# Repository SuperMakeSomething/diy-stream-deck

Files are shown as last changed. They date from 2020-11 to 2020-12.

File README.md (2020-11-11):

# DIY Stream Deck
by: Alex - Super Make Something

date: November 9, 2020

license: Creative Commons - Attribution - Non-Commercial.  More information available at: http://creativecommons.org/licenses/by-nc/3.0/

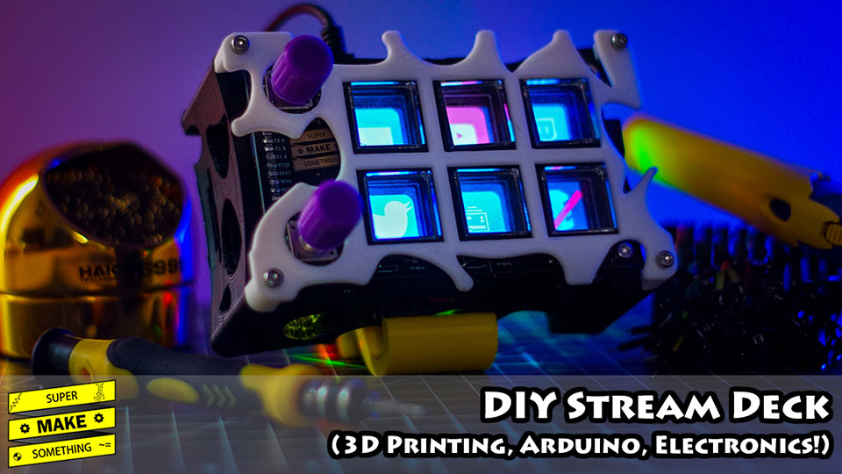
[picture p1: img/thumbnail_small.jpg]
Banner


Arduino code, icon templates, and programming instructions for the DIY Stream Deck featured in Super Make Something Episode 22!

The project video can be found [here](https://youtu.be/_NqYtvLnY5k)!

If you like projects like these, consider subscribing to the Super Make Something YouTube page [here](https://www.youtube.com/supermakesomething?sub_confirmation=1) for more cool builds!  To support more projects like this please consider becoming a [Patron](https://www.patreon.com/SuperMakeSomething).

## Introduction
Arguably one of the best streaming tools besides a camera, microphone, and lights is a Stream Deck, a macro keyboard with an LCD screen behind the buttons, which allows users to program custom shortcuts to control their streaming software and various other applications.  Unfortunately this surge in interest has made these devices either difficult to find or very expensive.  Because of this, I decided to create an open source version, which will hopefully make it easier for those interesting in streaming to go live online, and to make it possible for individuals to create the custom Stream Deck that best suits their streaming needs.

This repository contains code and icon templates required to build your own DIY Stream Deck.  Information found in this repository accompanies the "DIY Stream Deck" build video on the Super Make Something YouTube page, which can be found here.

## Installation instructions and required libraries
Write-up coming soon!  In the meantime, please check out the project video [here](https://youtu.be/_NqYtvLnY5k) for step-by-step instructions about how to build this project.

## Bill of materials
- PCBs: https://bit.ly/2JKsyOw
- 3D Printed Files: https://www.thingiverse.com/thing:4650060
- 3.5in TFT LCD Screen: https://amzn.to/3ke75tS
- Arduino Pro Micro: https://amzn.to/35e6Vys
- Arduino Nano: https://amzn.to/3eHZF0K
- SD Card Breakout Board: https://amzn.to/3kb2Orj
- 6mm Push-Buttons: https://amzn.to/2Ilm4VO
- Rotary Encoder with Push-Button: https://amzn.to/35j7Xtf
- Male/Female Header Kit: https://amzn.to/35ezw6T
- Ribbon Cable: https://amzn.to/2GPOrLq
- 4GB Micro SD Card: https://amzn.to/35eC2tS
- M2 Screw Kit: https://amzn.to/2GKlz77
- M3 Screw Kit: https://amzn.to/2GNitiQ
- Hatchbox Black PLA: https://amzn.to/35fGM2h
- Hatchbox White PLA: https://amzn.to/2InWG1n
- Color Changing PLA: https://amzn.to/35fNuoM
- Resistor Kit (Optional): https://amzn.to/2UcVQY2
- Slow Flash RGB LEDs (Optional): https://amzn.to/2Uep7l2
- 20x20mm Acrylic Squares: https://litko.net/

(All Amazon links are affiliate links.)

## Conclusion
Hopefully you found this project useful!  If you enjoyed this tutorial, consider subscribing to Super Make Something on YouTube [here](https://www.youtube.com/supermakesomething?sub_confirmation=1) for more cool builds!  If you _really_ liked this tutorial and want to support future projects, you can become a [patron on Patreon](https://www.patreon.com/SuperMakeSomething).

If you have any questions or comments, I can most easily be reached on [Twitter](https://twitter.com/supermakesmthng) or [Instagram](https://www.instagram.com/supermakesomething/).  For items or issues specifically related to this project, please leaving your questions in the comments of the accompanying YouTube video so that they can be referenced by others during their own builds.

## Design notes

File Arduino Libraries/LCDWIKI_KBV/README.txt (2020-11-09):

This is a library for the lcd display.
This library support these lcd controller:
ILI9325 
ILI9328 
ILI9341 
HX8357D 
HX8347G 
HX8347I 
ILI9486 
ST7735S 
 
Check out the file of LCDWIKI KBV lib Requirements for our tutorials and wiring diagrams.

These displays use 8-bit and 16-bit parallel to communicate, 12 or 13 pins are required to interface (RST is optional).
check out the file of lcd_mode.h for switching between 8bit mode and 16 bit mode.
Basic functionally of this library was origianlly based on the demo-code of Adafruit GFX lib and Adafruit TFTLCD lib.  

MIT license, all text above must be included in any redistribution

To download. click the DOWNLOADS button in the top right corner, rename the uncompressed folder LCDWIKI_KBV. Check that the LCDWIKI_KBV folder contains LCDWIKI_KBV.cpp and LCDWIKI_KBV.h

Place the LCDWIKI_KBV library folder your <arduinosketchfolder>/libraries/ folder. You may need to create the libraries subfolder if its your first library. Restart the IDE

Also requires the LCDWIKI_GUI library for Arduino. 
https://github.com/lcdwiki/LCDWIKI_gui

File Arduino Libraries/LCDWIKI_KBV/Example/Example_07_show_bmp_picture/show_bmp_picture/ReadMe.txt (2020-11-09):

ReadMe:
"ShowBMP"example need to read BMP files from SDcard.
so, firstly,you should format your SD-card into fat16 or fat32.
then copy the flower.bmp,RedRose.bmp,tiger.bmp,tree.bmp into your SD-card.

Attention:
This Example only support the Arduino UNO board,not support the Mega2560,Because they use different SPI bus.

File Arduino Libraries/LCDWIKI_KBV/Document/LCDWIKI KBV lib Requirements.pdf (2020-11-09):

# LCDWIKI KBV lib Requirements

the 8bit mode connections for shield

Lcd modules pin | Arduino
UNO | MEGA
LCD_D0 | D8 | D8
LCD_D1 | D9 | D9
LCD_D2 | D10 | D10
LCD_D3 | D11 | D11
LCD_D4 | D4 | D4
LCD_D5 | D13 | D13
LCD_D6 | D6 | D6
LCD_D7 | D7 | D7
LCD_RST | D5 | D5
LCD_CS | A3 | A3
LCD_RS | A2 | A2
LCD_WR | A1 | A1
LCD_RD | A0 | A0

the 8bit mode connections for breakout board

Lcd modules pin | Arduino
UNO | MEGA
LCD_D0 | D8 | D8
LCD_D1 | D9 | D9
LCD_D2 | D2 | D2
LCD_D3 | D3 | D3
LCD_D4 | D4 | D4
LCD_D5 | D5 | D5
LCD_D6 | D6 | D6
LCD_D7 | D7 | D7
LCD_RST | Any free pin
LCD_CS | Any free pin
LCD_RS | Any free pin
LCD_WR | Any free pin
LCD_RD | Any free pin

In this library,the 16bit mode only can use in Arduino Mega board.

the 16bit mode connections for shield and breakout board

Lcd modules pin | Arduino MEGA
shield | breakout board
DB0 | D37 | D37
DB1 | D36 | D36
DB2 | D35 | D35
DB3 | D34 | D34
DB4 | D33 | D33
DB5 | D32 | D32
DB6 | D31 | D31
DB7 | D30 | D30
DB8 | D22 | D22
DB9 | D23 | D23
DB10 | D24 | D24
DB11 | D25 | D25
DB12 | D26 | D26
DB13 | D27 | D27
DB14 | D28 | D28
DB15 | D29 | D29
RST | D5 | Any free pin
CS | D41 | Any free pin
RS | D38 | Any free pin
WR | D40 | Any free pin
RD | D43 | Any free pin

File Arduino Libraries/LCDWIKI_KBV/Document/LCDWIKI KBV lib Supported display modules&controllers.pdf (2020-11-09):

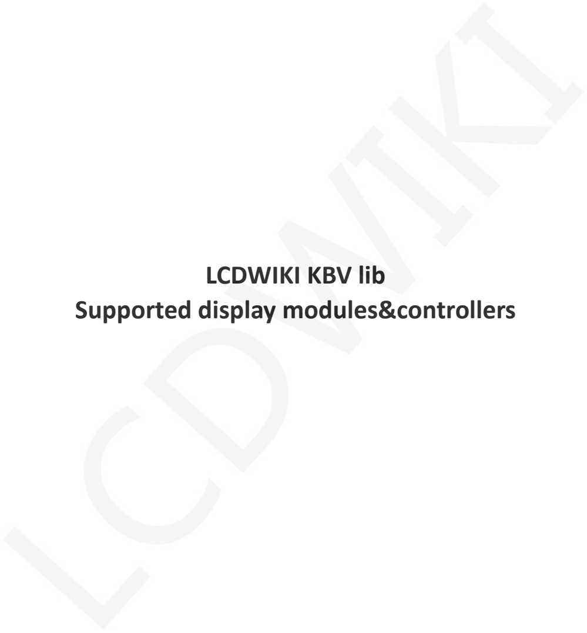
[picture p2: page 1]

# LCDWIKI KBV lib Supported display modules&controllers

### 1. IMPORTANT

### 2. Supported display modules&controllers

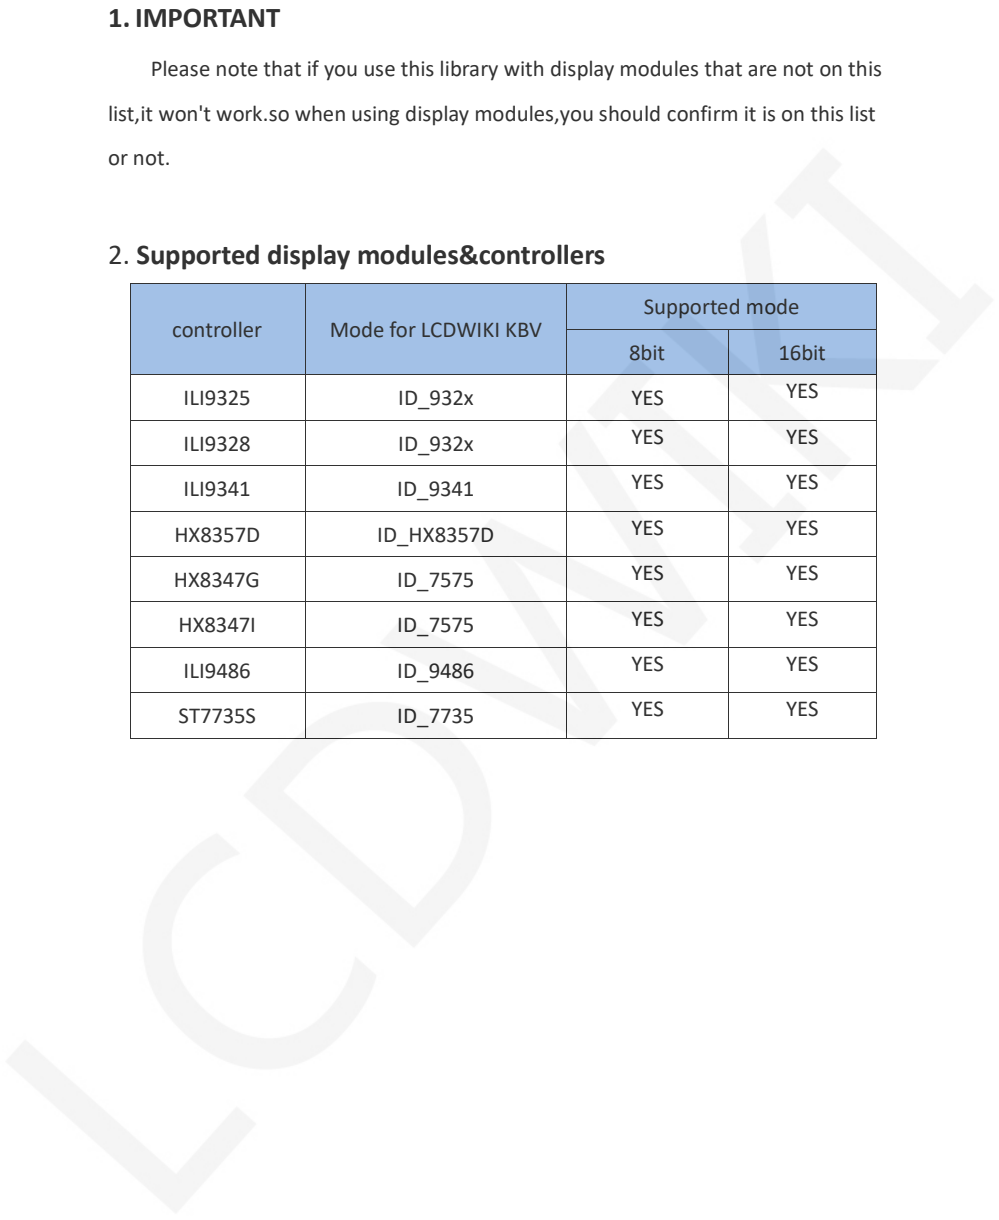
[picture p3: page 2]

Please note that if you use this library with display modules that are not on this

list,it won't work.so when using display modules,you should confirm it is on this list

or not.

controller | Mode for LCDWIKI KBV | Supported mode
8bit | 16bit
ILI9325 | ID_932x | YES | YES
ILI9328 | ID_932x | YES | YES
ILI9341 | ID_9341 | YES | YES
HX8357D | ID_HX8357D | YES | YES
HX8347G | ID_7575 | YES | YES
HX8347I | ID_7575 | YES | YES
ILI9486 | ID_9486 | YES | YES
ST7735S | ID_7735 | YES | YES

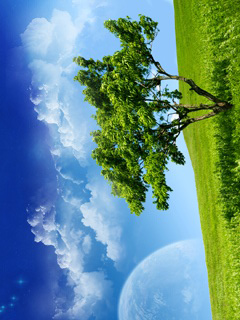
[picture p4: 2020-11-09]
Arduino Libraries/LCDWIKI_KBV/Example/Example_07_show_bmp_picture/show_bmp_picture/PIC_240x320/tree.bmp

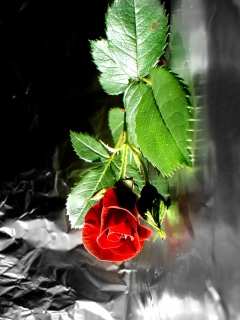
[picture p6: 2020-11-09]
Arduino Libraries/LCDWIKI_KBV/Example/Example_07_show_bmp_picture/show_bmp_picture/PIC_240x320/RedRose.bmp

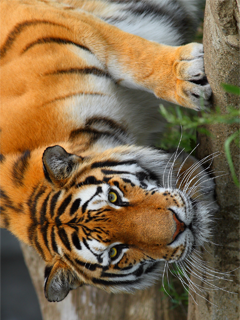
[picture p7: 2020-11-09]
Arduino Libraries/LCDWIKI_KBV/Example/Example_07_show_bmp_picture/show_bmp_picture/PIC_240x320/tiger.bmp

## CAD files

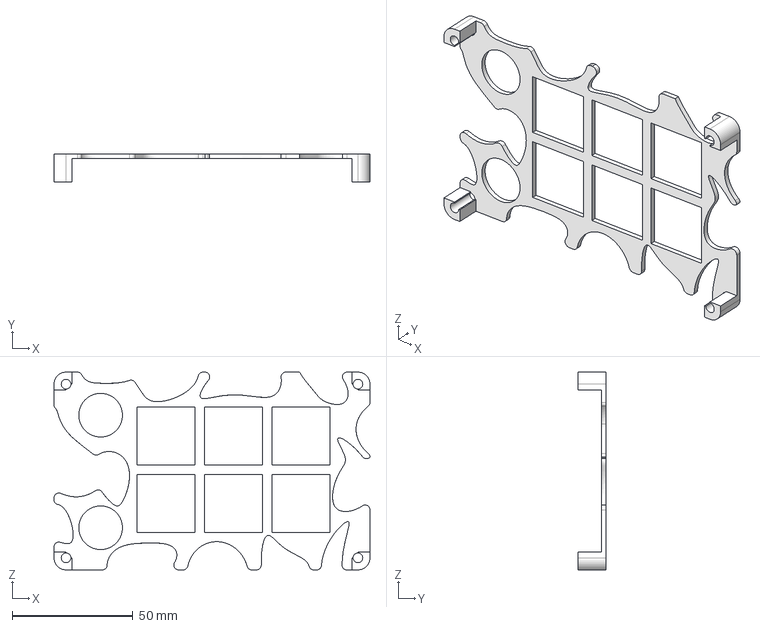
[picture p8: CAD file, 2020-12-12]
CAD/STEP Files/PM-1002 - Stream Deck Cover.step
131.0 x 11.8 x 82.0 mm

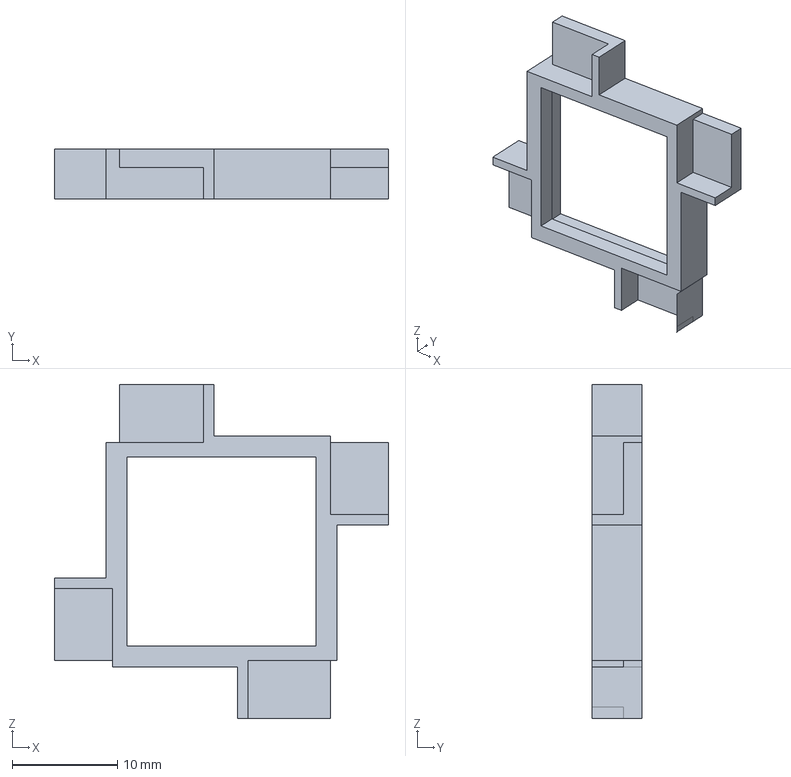
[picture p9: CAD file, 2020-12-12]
CAD/STEP Files/PM-1003 - Button Cover.step
31.8 x 4.75 x 31.8 mm

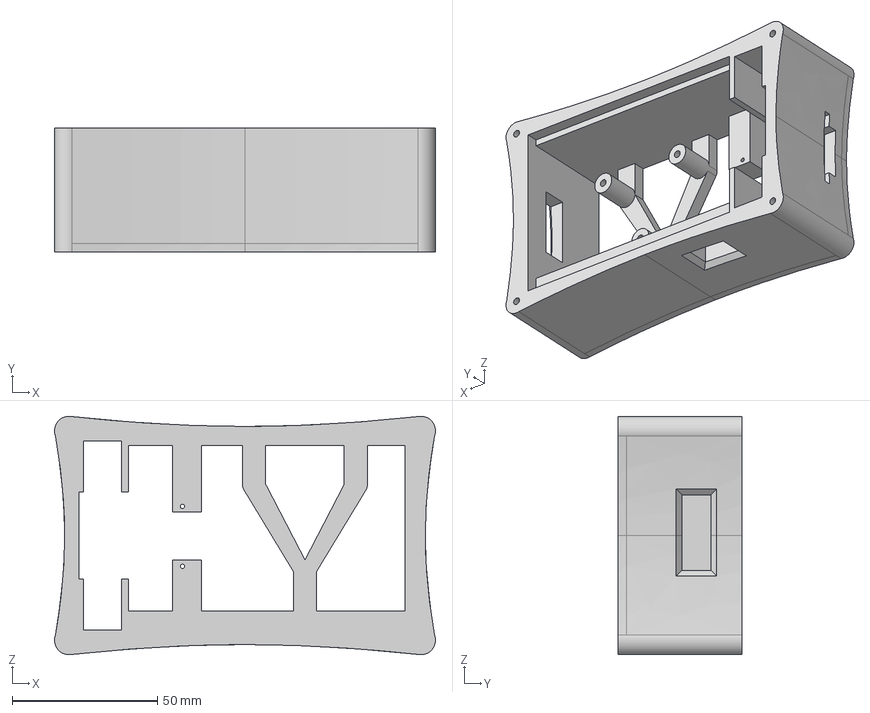
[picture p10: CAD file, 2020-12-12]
CAD/STEP Files/PM-1001a - Housing.step
131.0 x 42.8 x 82.0 mm

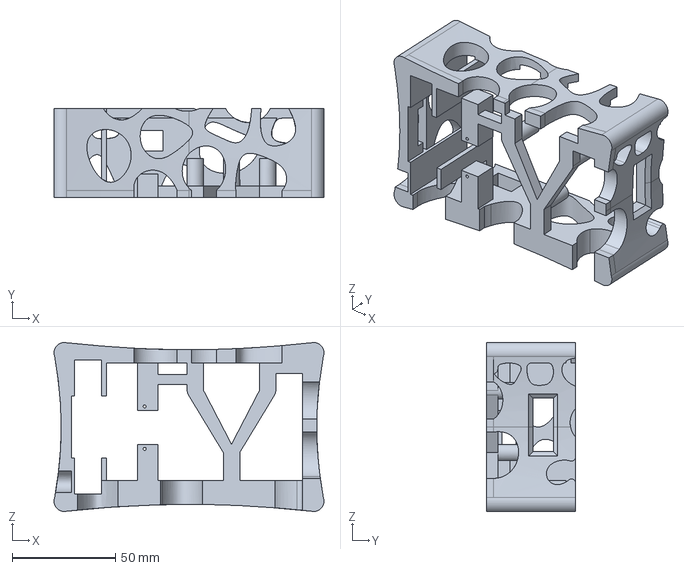
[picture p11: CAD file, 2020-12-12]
CAD/STEP Files/PM-1001b - Voronoi Housing.step
131.0 x 43.3 x 82.0 mm

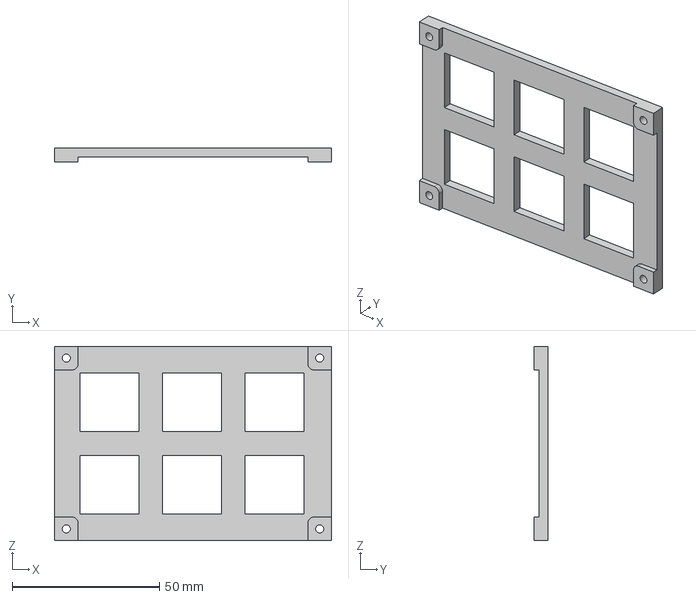
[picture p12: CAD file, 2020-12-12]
CAD/STEP Files/PM-1005 - Button PCB Spacer.step
94.0 x 4.75 x 66.0 mm

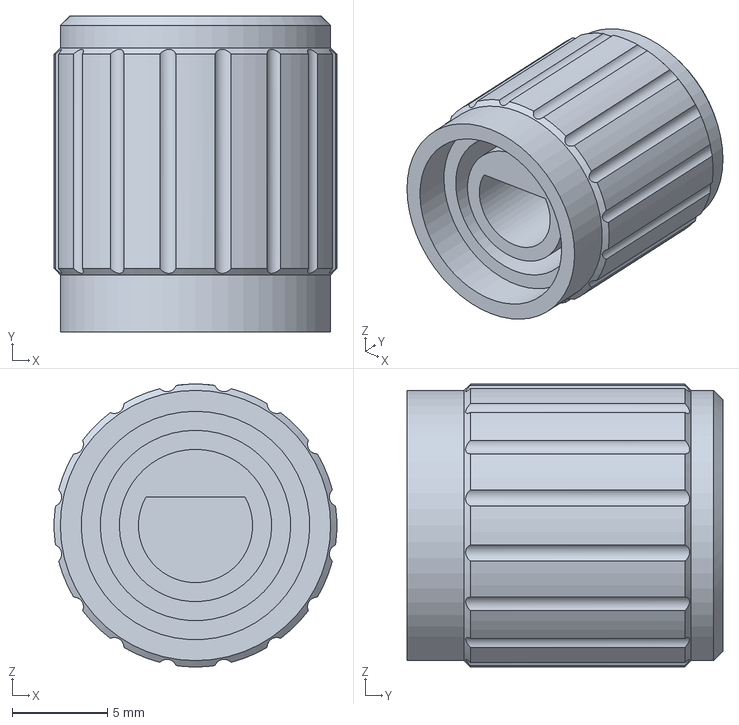
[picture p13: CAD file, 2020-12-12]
CAD/STEP Files/PM-1004 - Encoder Knob.step
14.8 x 16.6 x 14.9 mm

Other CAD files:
CAD/STL Files/PM-1001a - Housing.stl
CAD/STL Files/PM-1001b - Voronoi Housing.stl
CAD/STL Files/PM-1002 - Stream Deck Cover.stl
CAD/STL Files/PM-1003 - Button Cover.stl
CAD/STL Files/PM-1004 - Encoder Knob.stl
CAD/STL Files/PM-1005 - Button PCB Spacer.stl

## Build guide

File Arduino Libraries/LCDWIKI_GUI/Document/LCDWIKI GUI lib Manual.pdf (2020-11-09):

# LCDWIKI GUI lib Manual

### 1.Introduction

The LCDWIKI GUI lib is the core graphics library for all our displays, providing a

common set of graphics primitives (points, lines, circles, etc.). It needs to be paired

with a hardware-specific library for each display device we carry (to handle the

lower-level functions).

The LCDWIKI GUI lib have the base class.so all functions in this lib should be

called by the subclass.

### 2.FUNCTIONS DECLARATION

definiens | LCDWIKI_GUI(void)
function | The main class constructor when using 8bit or 16bit or spi display modules.
parameters | None
returned value | None
notes | None
definiens | virtual uint16_t Color_To_565(uint8_t r, uint8_t g, uint8_t b)
function | Pass three 8bits colour value and get the 16bits colour value
parameters | r : the 8bits red value g : the 8bits green value b : the 8bits blue value
returned value | The 16bits colour value(rrrrrggggggbbbbb)
notes | This is virtual function and it is defined by the subclass
definiens | virtual void Draw_Pixe(int16_t x, int16_t y, uint16_t color)
function | Using color value to draw a single point
parameters | x : the x coordinate of the piexl y : the y coordinate of the piexl color : the color value of the piexl
returned value | None
notes | This is virtual function and it is defined by the subclass

definiens | virtual void Fill_Rect(int16_t x, int16_t y, int16_t w, int16_t h, uint16_t color)
function | Using color value to draw a filled rectangle with w width and h height in x and y coordinate
parameters | x : the x coordinate of the start-corner y : the y coordinate of the start-corner w : the width of the rectangle h : the height of the rectangle color : the color value of the filled rectangle
returned value | None
notes | This is virtual function and it is defined by the subclass
definiens | virtual void Set_Addr_Window(int16_t x1, int16_t y1, int16_t x2, int16_t y2)
function | Set display area bewteen two point
parameters | x1 : the x coordinate of the start-corner y1 : the y coordinate of the start-corner x2 : the x coordinate of the end-corner y2 : the y coordinate of the end-corner
returned value | None
notes | This is virtual function and it is defined by the subclass

definiens | virtual void Push_Any_Color(uint16_t * block, int16_t n, bool first, uint8_t flags)
function | Set a large number of color values at a time
parameters | block : the array of colour values n : the number of colour values first : 1- First set the command of write color value 0-have set the command of write color value flags : 0-read color value from RAM 1-read color value from flash
returned value | None
notes | This is virtual function and it is defined by the subclass
definiens | virtual int16_t Read_GRAM(int16_t x, int16_t y, uint16_t *block, int16_t w, int16_t h)
function | Read colour value from GRAM
parameters | x : the x coordinate of the start-corner y : the y coordinate of the start-corner block : the array of saving colour value w : the width of the Read area h : the heigth of the Read area
returned value | 0-successful
notes | This is virtual function and it is defined by the subclass

definiens | virtual int16_t Get_Height(void) const
function | Get the display height
parameters | None
returned value | The diaplay height
notes | This is virtual function and it is defined by the subclass
definiens | virtual int16_t Get_Width(void) const
function | Get the display width
parameters | None
returned value | The diaplay width
notes | This is virtual function and it is defined by the subclass
definiens | void Set_Draw_color(uint16_t color)
function | Set the drawing color
parameters | color : the 16bits Drawing color value
returned value | None
notes | None
definiens | void Set_Draw_color(uint16_t color)
function | Set the drawing color
parameters | color : the 16bits Drawing color value
returned value | None

notes | None
definiens | void Set_Draw_color(uint8_t r, uint8_t g, uint8_t b)
function | Set the drawing color
parameters | r : the 8bits red value g : the 8bits green value b : the 8bits blue value
returned value | None
notes | None
definiens | uint16_t Get_Draw_color(void) const
function | get the drawing color
parameters | None
returned value | The 16bits drawing color value(rrrrrggggggbbbbb)
notes | None
definiens | void Draw_Pixel(int16_t x, int16_t y)
function | Draw a single point
parameters | x : the x coordinate of the piexl y : the y coordinate of the piexl
returned value | None
notes | None

definiens | uint16_t Read_Pixel(int16_t x, int16_t y)
function | Get the color value of a single point
parameters | x : the x coordinate of the piexl y : the y coordinate of the piexl
returned value | 16bits color value of a single point
notes | The mould must be readable,this functon can be used normally.
definiens | void Draw_Fast_VLine(int16_t x, int16_t y, int16_t h)
function | Quickly draw out a vertical line
parameters | x : the x coordinate of the start point y : the y coordinate of the start point h : the height of the line
returned value | None
notes | None
definiens | void Draw_Fast_HLine(int16_t x, int16_t y, int16_t w)
function | Quickly draw out a horizontal line
parameters | x : the x coordinate of the start point y : the y coordinate of the start point h : the width of the line
returned value | None
notes | None

definiens | void Fill_Screen(uint16_t color)
function | Fill whole screen area
parameters | color : 16bits color value
returned value | None
notes | None
definiens | void Fill_Screen(uint8_t r, uint8_t g, uint8_t b)
function | Fill whole screen area
parameters | r : the 8bits red value g : the 8bits green value b : the 8bits blue value
returned value | None
notes | The r,g,b is converted to 16bits value(rrrrrggggggbbbbb)
definiens | void Draw_Line(int16_t x1, int16_t y1, int16_t x2, int16_t y2)
function | Draw a line be
parameters | r : the 8bits red value g : the 8bits green value b : the 8bits blue value
returned value | None
notes | The r,g,b is converted to 16bits value(rrrrrggggggbbbbb)

definiens | void Draw_Rectangle(int16_t x1, int16_t y1, int16_t x2, int16_t y2)
function | Draw a rectangle between two points
parameters | x1 : the x coordinate of the start point y1 : the y coordinate of the start point x2 : the x coordinate of the end point y2 : the y coordinate of the end point
returned value | None
notes | None
definiens | void Fill_Rectangle(int16_t x1, int16_t y1, int16_t x2, int16_t y2)
function | Draw a filled rectangle between two points
parameters | x1 : the x coordinate of the start point y1 : the y coordinate of the start point x2 : the x coordinate of the end point y2 : the y coordinate of the end point
returned value | None
notes | None
definiens | void Draw_Round_Rectangle(int16_t x1, int16_t y1, int16_t x2, int16_t y2, uint8_t radius)
function | Draw a rectangle with slightly rounded corners between two points

parameters | x1 : the x coordinate of the start point y1 : the y coordinate of the start point x2 : the x coordinate of the end point y2 : the y coordinate of the end point radius : radius of the rounded corners, the minimum value is 5
returned value | None
notes | If the radius is smaller than the minimum value ,the round rectangle will not be drawn
definiens | void Fill_Round_Rectangle(int16_t x1, int16_t y1, int16_t x2,int16_t y2, int16_t radius)
function | Draw a filled rectangle with slightly rounded corners between two points
parameters | x1 : the x coordinate of the start point y1 : the y coordinate of the start point x2 : the x coordinate of the end point y2 : the y coordinate of the end point radius : radius of the rounded corners, the minimum value is 5
returned value | None
notes | If the radius is smaller than the minimum value ,the round rectangle will not be drawn
definiens | void Draw_Circle(int16_t x, int16_t y, int16_t radius)
function | Draw a circle with a specified radius
parameters | x : the x coordinate of the center of the circle y : the y coordinate of the center of the circle

| radius : radius of the circle
returned value | None
notes | None
definiens | void Draw_Circle_Helper(int16_t x0, int16_t y0, int16_t radius, uint8_t cornername)
function | Draw rounded corners with a specified radius
parameters | x0 : the x coordinate of the center of the rounded corner y0 : the y coordinate of the center of the rounded corner radius : radius of the rounded corners, the minimum value is 5 cornername : the order number of the rounded corners, 1 : top left corner 2 : top right corner 4 : lower right corner 8 : lower left quarter
returned value | None
notes | If the radius is smaller than the minimum value ,the round rectangle will not be drawn.you can draw several rounded corners at a time
definiens | void Fill_Circle(int16_t x, int16_t y, int16_t radius)
function | Draw a filled circle with a specified radius
parameters | x : the x coordinate of the center of the circle y : the y coordinate of the center of the circle radius : radius of the circle

returned value | None
notes | None
definiens | void Fill_Circle_Helper(int16_t x0, int16_t y0, int16_t r, uint8_t cornername,int16_t delta)
function | Draw filled rounded corners with a specified radius
parameters | x0 : the x coordinate of the center of the rounded corner y0 : the y coordinate of the center of the rounded corner r : radius of the rounded corner cornername : the order number of the rounded corners 1 : right rounded corner 2 : left rounded corner delta : Non - circular area height
returned value | None
notes | you can draw filled several rounded corners at a time
definiens | void Draw_Triangle(int16_t x0, int16_t y0, int16_t x1, int16_t y1,int16_t x2, int16_t y2)
function | Draw a triangle between three points
parameters | x0 : the x coordinate of the start point of the triangle bottom y0 : the y coordinate of the start point of the triangle bottom x1 : the x coordinate of the triangular vertex y1 : the x coordinate of the triangular vertex x2 : the x coordinate of the end point of the triangle bottom y2 : the y coordinate of the end point of the triangle bottom

returned value | None
notes | None
definiens | void Fill_Triangle(int16_t x0, int16_t y0, int16_t x1, int16_t y1,int16_t x2, int16_t y2)
function | Draw a filled triangle between three points
parameters | x0 : the x coordinate of the start point of the triangle bottom y0 : the y coordinate of the start point of the triangle bottom x1 : the x coordinate of the triangular vertex y1 : the y coordinate of the triangular vertex x2 : the x coordinate of the end point of the triangle bottom y2 : the y coordinate of the end point of the triangle bottom
returned value | None
notes | None
definiens | void Draw_Bit_Map(int16_t x, int16_t y, int16_t sx, int16_t sy, const uint16_t *data, int16_t scale)
function | Draw a bitmap on the screen
parameters | x : the x coordinate of the top left corner of bitmap y : the y coordinate of the top left corner of bitmap sx : width of the bitmap sy : height of the bitmap data : array containing the bitmap-data scale : scaling factor. Each pixel in the bitmap will be drawn as <scale>x<scale> pixels on screen

returned value | None
notes | None
definiens | void Set_Text_Cousur(int16_t x, int16_t y)
function | Set text position in screen
parameters | x : the x coordinate of the text y : the y coordinate of the text
returned value | None
notes | None
definiens | int16_t Get_Text_X_Cousur(void) const
function | get the x coordinate of the text
parameters | None
returned value | the x coordinate of the text
notes | None
definiens | int16_t Get_Text_Y_Cousur(void) const
function | get the y coordinate of the text
parameters | None
returned value | the y coordinate of the text
notes | None

definiens | void Set_Text_colour(uint16_t color)
function | Set the text color value
parameters | Color : the 16bits color value of the text
returned value | None
notes | None
definiens | void Set_Text_colour(uint8_t r, uint8_t g, uint8_t b)
function | Set the text color value
parameters | r : the 8bits red value of the text g : the 8bits green value of the text b : the 8bits blue value of the text
returned value | None
notes | None
definiens | uint16_t Get_Text_colour(void) const
function | get the text color value
parameters | None
returned value | the 16bits color value of the text
notes | None
definiens | void Set_Text_Back_colour(uint16_t color)
function | set the background color value of the text

parameters | Color : the 16bits background color value of the text
returned value | None
notes | None
definiens | void Set_Text_Back_colour(uint8_t r, uint8_t g, uint8_t b)
function | set the background color value of the text
parameters | r : the 8bits red value of the text g : the 8bits green value of the text b : the 8bits blue value of the text
returned value | None
notes | None
definiens | void Set_Text_Back_colour(uint8_t r, uint8_t g, uint8_t b)
function | set the background color value of the text
parameters | r : the 8bits red value of the text g : the 8bits green value of the text b : the 8bits blue value of the text
returned value | None
notes | None
definiens | uint16_t Get_Text_Back_colour(void) const
function | get the background color value of the text
parameters | None

returned value | the 16bits background color value of the text
notes | None
definiens | void Set_Text_Size(uint8_t s)
function | set the size of the text
parameters | s : the size of the text
returned value | None
notes | None
definiens | uint8_t Get_Text_Size(void) const
function | Get the size of the text
parameters | None
returned value | The size value of the text
notes | None
definiens | void Set_Text_Mode(boolean mode)
function | Set overlap mode of the text
parameters | mode : 0-no overlap 1-overlap
returned value | None
notes | If the mode is overlap,the background color setting of the text is invalid.

definiens | boolean Get_Text_Mode(void) const
function | get the overlap mode value of the text
parameters | None
returned value | 0-no overlap 1-overlap
notes | If the mode is overlap,the background color setting of the text is invalid.
definiens | size_t Print(uint8_t *st, int16_t x, int16_t y)
function | Print a string at the specified coordinates
parameters | st : the string to print x : the x coordinate of the top left corner of the first character y : the y coordinate of the top left corner of the first character
returned value | The Number of characters
notes | You can use the literals LEFT, CENTER and RIGHT as the x-coordinate to align the string on the screen
definiens | void Print_String(const uint8_t *st, int16_t x, int16_t y)
function | Print a constant string at the specified coordinates
parameters | st : the constant string to print x : the x coordinate of the top left corner of the first character y : the y coordinate of the top left corner of the first character
returned value | None
notes | You can use the literals LEFT, CENTER and RIGHT as the x-coordinate to align the string on the screen

definiens | void Print_String(uint8_t *st, int16_t x, int16_t y)
function | Print a string at the specified coordinates
parameters | st : the string to print x : the x coordinate of the top left corner of the first character y : the y coordinate of the top left corner of the first character
returned value | None
notes | You can use the literals LEFT, CENTER and RIGHT as the x-coordinate to align the string on the screen
definiens | void Print_String(String st, int16_t x, int16_t y)
function | Using string class to print a string at the specified coordinates
parameters | st : the string object x : the x coordinate of the top left corner of the first character y : the y coordinate of the top left corner of the first character
returned value | None
notes | You can use the literals LEFT, CENTER and RIGHT as the x-coordinate to align the string on the screen
definiens | void Print_Number_Int(long num, int16_t x, int16_t y, int16_t length, uint8_t filler, int16_t system)
function | Print a specified length Integral number at the specified coordinates
parameters | num : the value to print (-2,147,483,648 to 2,147,483,647) INTEGERS ONLY

x : the x coordinate of the top left corner of the first

number/sign

y : the y coordinate of the top left corner of the first

number/sign

length : minimum number of digits/characters (including sign)

to display

filler : filler character to use to get the minimum length. The

character will be inserted in front of the number, but after the

sign. Default is ' ' (space).

system : 8-octal

10- decimal

16- hexadecimal
returned value | None
notes | You can use the literals LEFT, CENTER and RIGHT as the x-coordinate to align the string on the screen
definiens | void Print_Number_Float(double num, uint8_t dec, int16_t x, int16_t y, uint8_t divider, int16_t length, uint8_t filler)
function | Print a specified length floating-point number at the specified coordinates.
parameters | num : the value to print(Supported range depends on the number of fractional digits used.Approx range is +/-2*(10^(9-dec))) dec : digits in the fractional part (1-5) 0 is not supported x : the x coordinate of the top left corner of the first number/sign y : the y coordinate of the top left corner of the first number/sign

| divider : Single character to use as decimal point. Default is '.' length : minimum number of digits/characters (including sign) to display filler : filler character to use to get the minimum length. The character will be inserted in front of the number, but after the sign. Default is ' ' (space).
returned value | None
notes | You can use the literals LEFT, CENTER and RIGHT as the x-coordinate to align the string on the screen
definiens | void Draw_Char(int16_t x, int16_t y, uint8_t c, uint16_t color,uint16_t bg, uint8_t size, boolean mode)
function | Draw a character at the specified coordinates.
parameters | x : the x coordinate of the top left corner of the character y : the y coordinate of the top left corner of the character c : the character to print color : the color value of the character to print bg : the background color value of the character to print size : the size of the character to print mode : 0-no overlap 1-overlap
returned value | None
notes | If the mode is overlap,the background color setting of the text is invalid.

definiens | size_t write(uint8_t c)
function | Write a character to print
parameters | c : the character to print
returned value | The statue of writing. 1-successful
notes | None
definiens | int16_t Get_Display_Width(void) const
function | Get the width of the screen
parameters | None
returned value | the width of the screen
notes | None
definiens | int16_t Get_Display_Height(void) const
function | Get the height of the screen
parameters | None
returned value | the height of the screen
notes | None

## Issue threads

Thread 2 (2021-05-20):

USB Compatibility

thatdecade, 2021-05-20:
Directly to my PC, I have a catch-22 situation as my USB 2.0 ports don't output enough power and the USB 3.0 ports are incompatible with the atmega32u4.

Workaround is using a powered USB 2.0 hub.

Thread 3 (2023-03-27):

Encoder.h not in package

Algesat, 2023-03-27:
Hi Alex, im trying to upload the sketch to the Arduino Leonardo (the keyboard controller) and cant upload it because it says Encoder.h is missing. Checked it and its not on the library of the project.

Can you share it or its enough with a generic one?

Closed 2023-03-28.

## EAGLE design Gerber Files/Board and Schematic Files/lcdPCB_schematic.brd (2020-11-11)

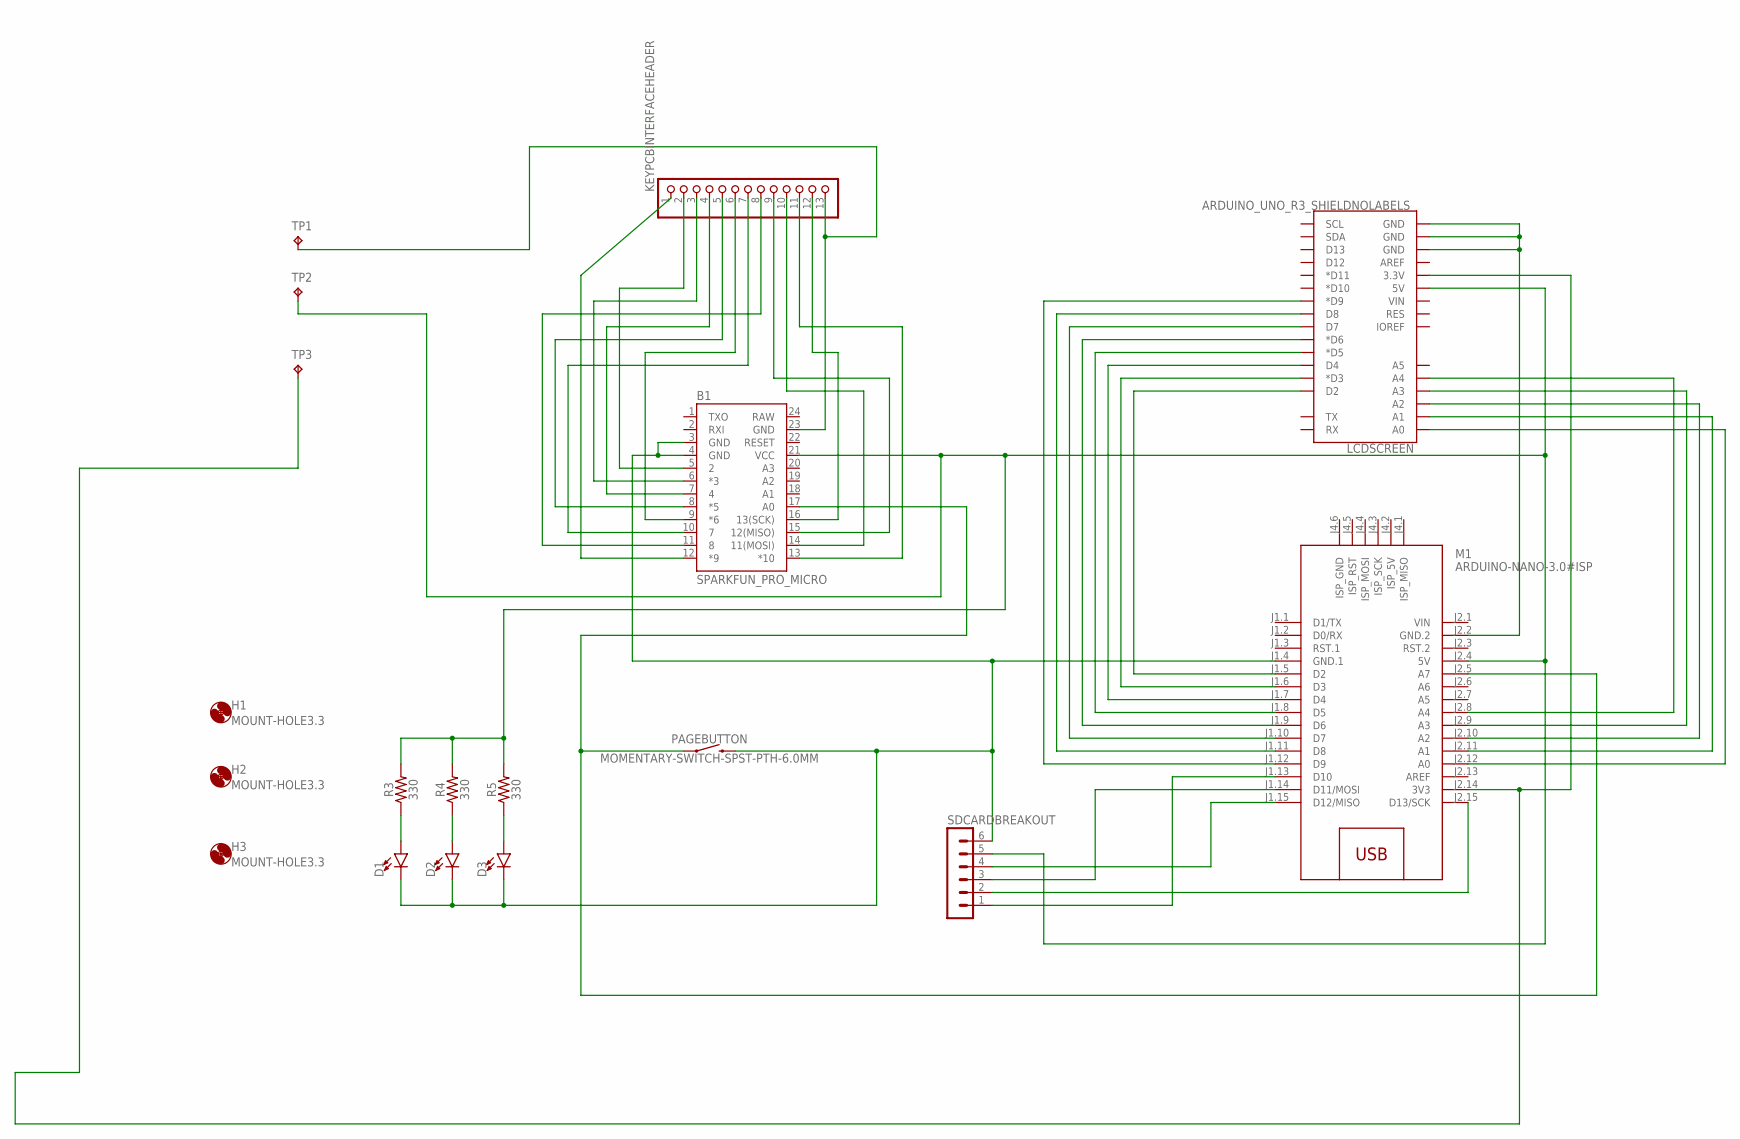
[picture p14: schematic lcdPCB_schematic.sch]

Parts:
B1: SPARKFUN_PRO_MICRO
D1, D2, D3: LED-3MM-NO_SILK; LED_3MM-NS
H1, H2, H3: MOUNT-HOLE3.3; 3,3
KEYPCBINTERFACEHEADER: PINHD-1X13; 1X13
LCDSCREEN: ARDUINO_UNO_R3_SHIELDNOLABELS; UNO_R3_SHIELD_NOLABELS
M1: ARDUINO-NANO-3.0#ISP
PAGEBUTTON: MOMENTARY-SWITCH-SPST-PTH-6.0MM; TACTILE_SWITCH_PTH_6.0MM
R3, R4, R5: 330; AXIAL-0.3
SDCARDBREAKOUT: MA06-1
TP1, TP2, TP3: TPTP20SQ; TP20SQ

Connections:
unnamed: LCDSCREEN.A0, M1.J2.12 (A0)
unnamed: LCDSCREEN.A1, M1.J2.11 (A1)
unnamed: LCDSCREEN.A2, M1.J2.10 (A2)
unnamed: LCDSCREEN.A3, M1.J2.9 (A3)
unnamed: LCDSCREEN.A4, M1.J2.8 (A4)
unnamed: LCDSCREEN.D2, M1.J1.5 (D2)
unnamed: LCDSCREEN.D3 (*D3), M1.J1.6 (D3)
unnamed: LCDSCREEN.D4, M1.J1.7 (D4)
unnamed: LCDSCREEN.D5 (*D5), M1.J1.8 (D5)
unnamed: LCDSCREEN.D6 (*D6), M1.J1.9 (D6)
unnamed: LCDSCREEN.D7, M1.J1.10 (D7)
unnamed: LCDSCREEN.D8, M1.J1.11 (D8)
unnamed: LCDSCREEN.D9 (*D9), M1.J1.12 (D9)
unnamed: M1.J1.13 (D10), SDCARDBREAKOUT.1
unnamed: M1.J2.15 (D13/SCK), SDCARDBREAKOUT.2
unnamed: M1.J1.14 (D11/MOSI), SDCARDBREAKOUT.3
unnamed: M1.J1.15 (D12/MISO), SDCARDBREAKOUT.4
unnamed: B1.3 (GND), B1.4 (GND), D1.K (C), D2.K (C), D3.K (C), M1.J1.4 (GND.1), PAGEBUTTON.3 (2), SDCARDBREAKOUT.6
unnamed: B1.21 (VCC), LCDSCREEN.5V, M1.J2.4 (5V), R3.P$2 (2), R4.P$2 (2), R5.P$2 (2), SDCARDBREAKOUT.5, TP2.TP
unnamed: LCDSCREEN.3.3V, M1.J2.14 (3V3), TP3.TP
unnamed: LCDSCREEN.GND@0 (GND), LCDSCREEN.GND@1 (GND), LCDSCREEN.GND@2 (GND), M1.J2.2 (GND.2)
unnamed: B1.12 (*9), KEYPCBINTERFACEHEADER.1
unnamed: B1.5 (2), KEYPCBINTERFACEHEADER.2
unnamed: B1.6 (*3), KEYPCBINTERFACEHEADER.3
unnamed: B1.7 (4), KEYPCBINTERFACEHEADER.4
unnamed: B1.8 (*5), KEYPCBINTERFACEHEADER.5
unnamed: B1.9 (*6), KEYPCBINTERFACEHEADER.6
unnamed: B1.10 (7), KEYPCBINTERFACEHEADER.7
unnamed: B1.11 (8), KEYPCBINTERFACEHEADER.8
unnamed: B1.13 (*10), KEYPCBINTERFACEHEADER.11
unnamed: B1.15 (12(MISO)), KEYPCBINTERFACEHEADER.9
unnamed: B1.14 (11(MOSI)), KEYPCBINTERFACEHEADER.10
unnamed: B1.16 (13(SCK)), KEYPCBINTERFACEHEADER.12
unnamed: B1.17 (A0), M1.J2.5 (A7), PAGEBUTTON.1
unnamed: B1.23 (GND), KEYPCBINTERFACEHEADER.13, TP1.TP
unnamed: D1.A, R3.P$1 (1)
unnamed: D2.A, R4.P$1 (1)
unnamed: D3.A, R5.P$1 (1)
RAW: B1.24 (RAW)
VIN: M1.J2.1 (VIN)

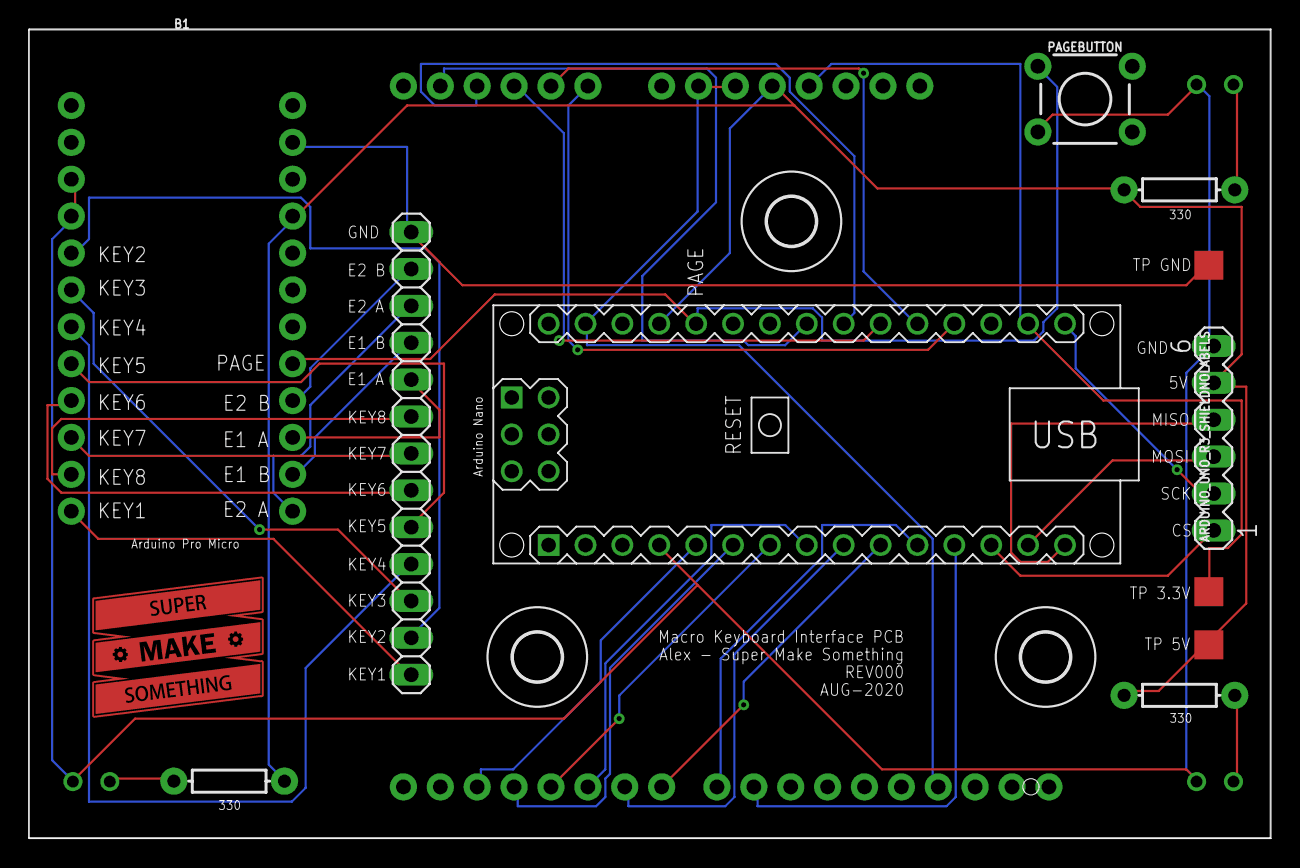
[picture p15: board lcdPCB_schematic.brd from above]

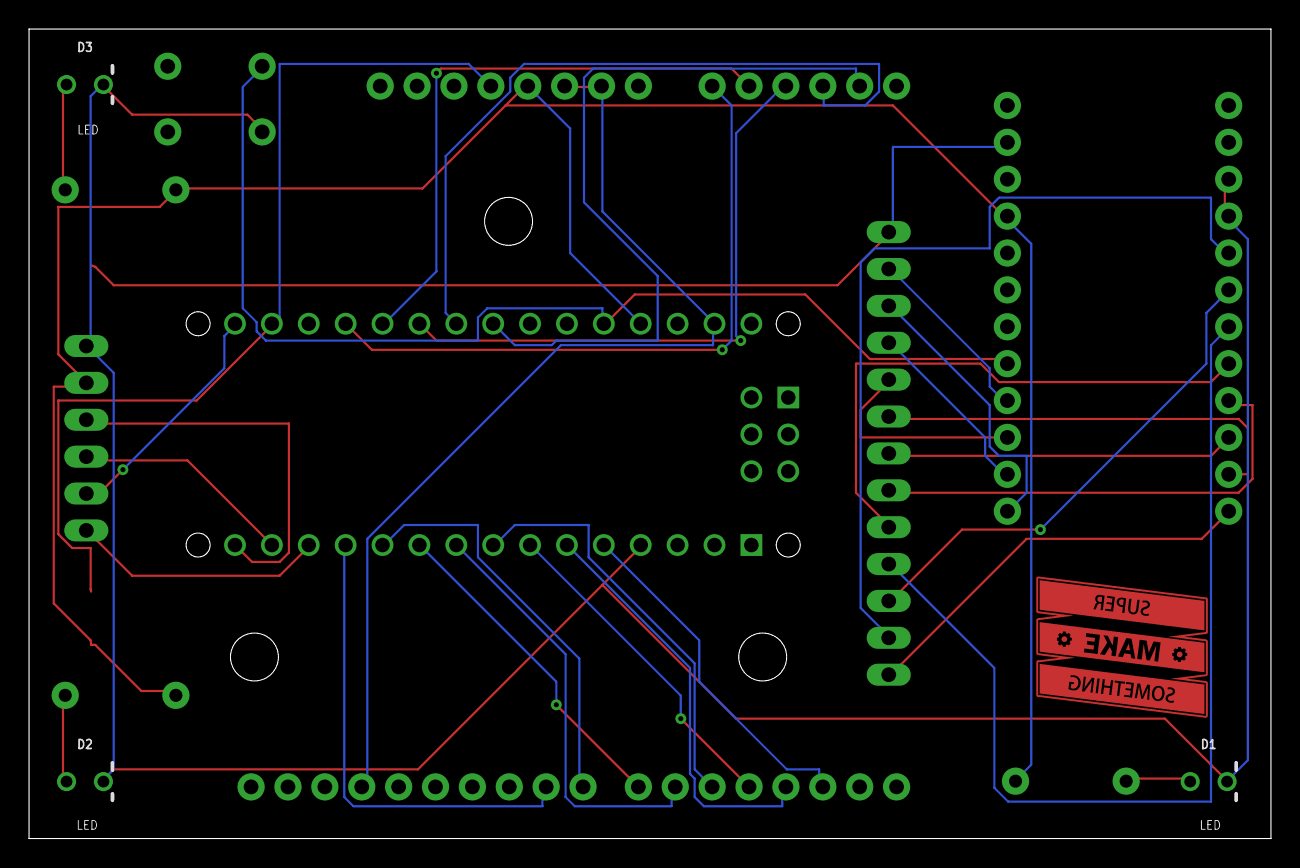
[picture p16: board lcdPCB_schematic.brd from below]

Board: 2 copper layers, 85.5 x 55.7 mm, 18 parts (3 on the bottom side), 38 nets.

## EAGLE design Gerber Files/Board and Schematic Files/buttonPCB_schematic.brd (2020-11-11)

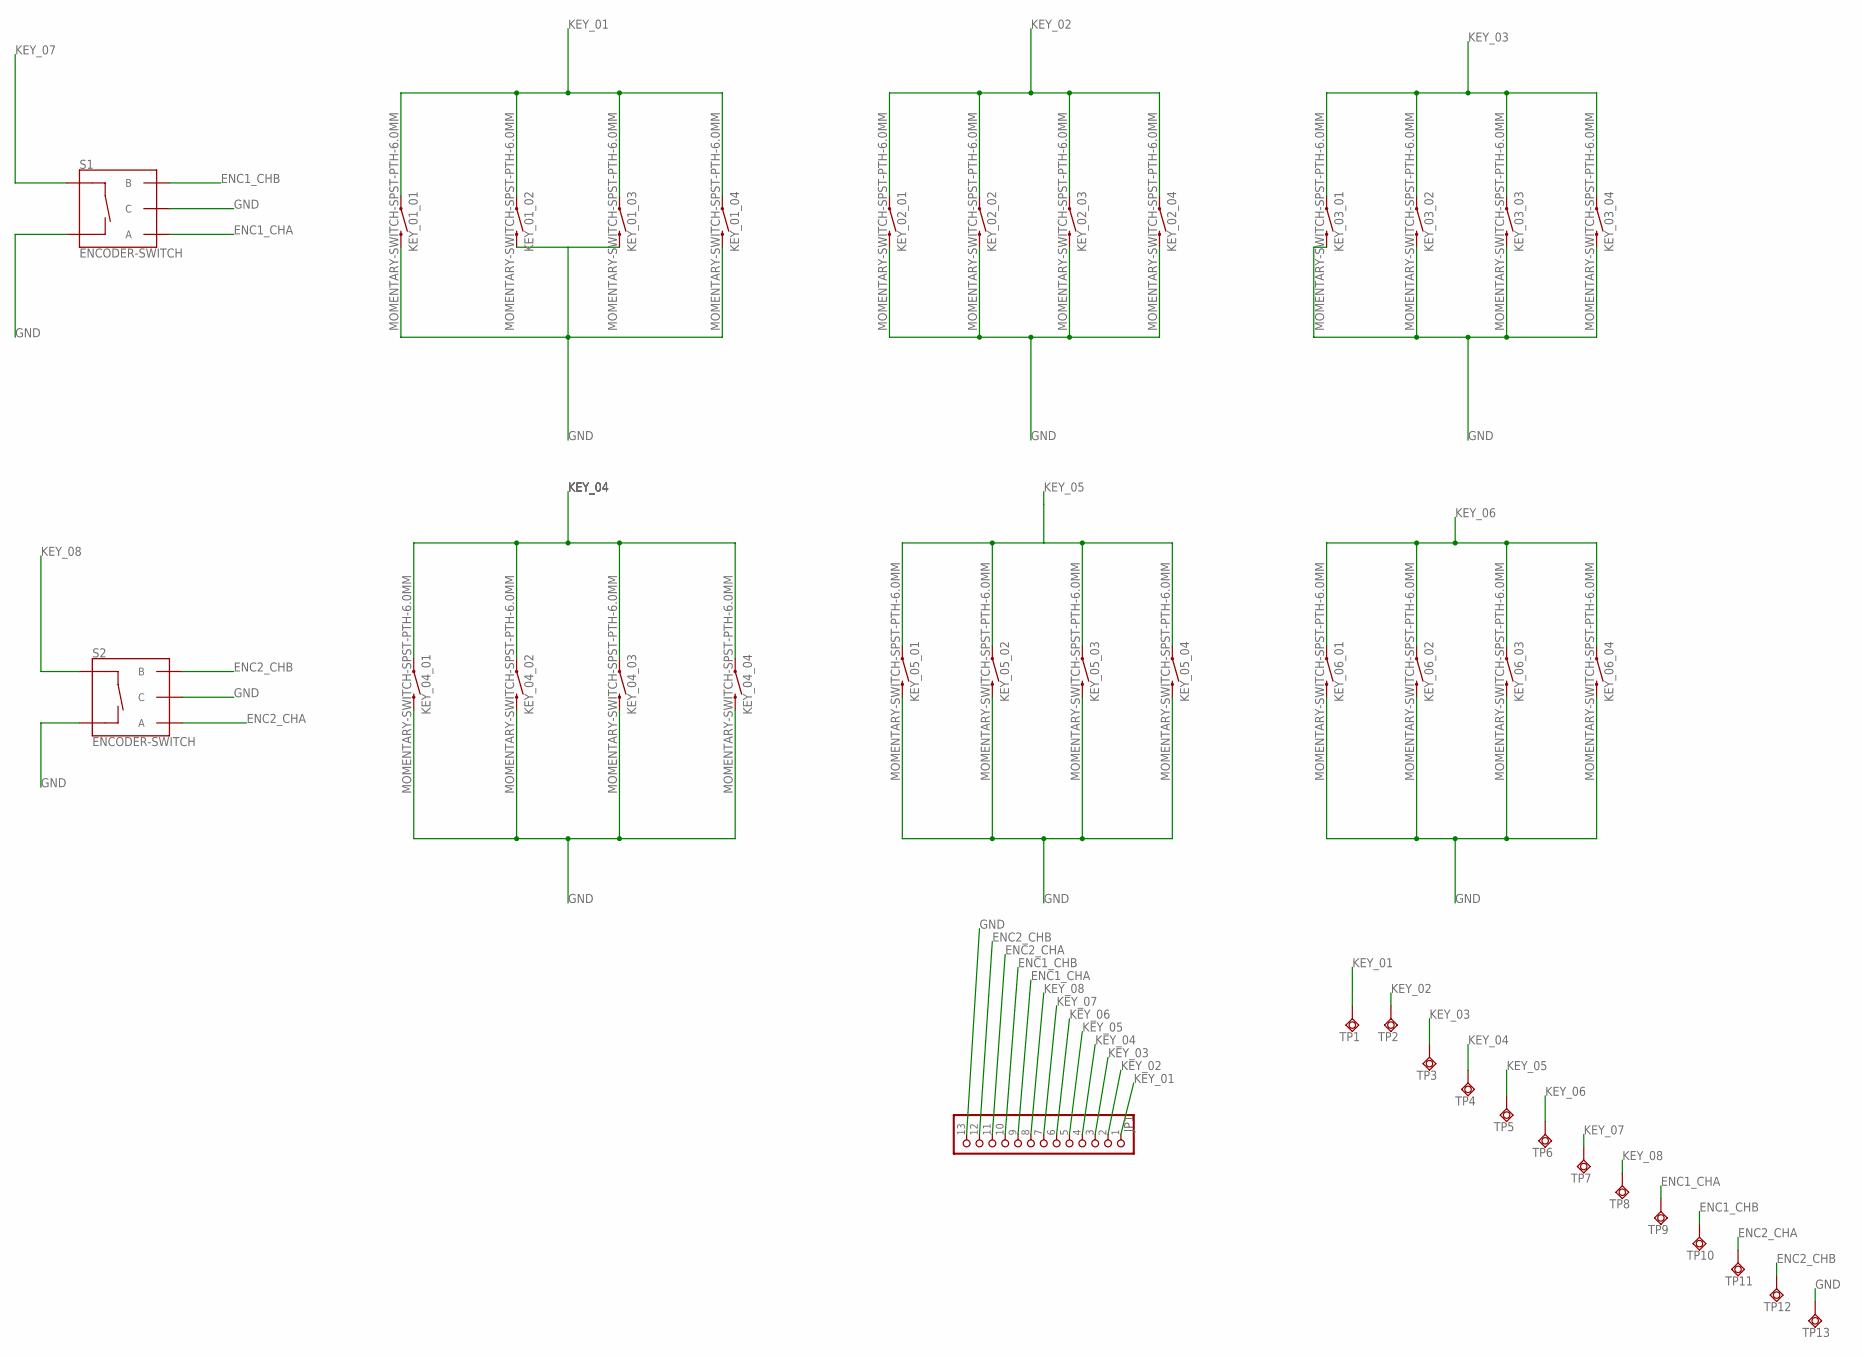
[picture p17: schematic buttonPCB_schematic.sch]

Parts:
JP1: PINHD-1X13; 1X13
KEY_01_01, KEY_01_02, KEY_01_03, KEY_01_04, KEY_02_01, KEY_02_02, KEY_02_03, KEY_02_04, KEY_03_01, KEY_03_02, KEY_03_03, KEY_03_04, KEY_04_01, KEY_04_02, KEY_04_03, KEY_04_04, KEY_05_01, KEY_05_02, KEY_05_03, KEY_05_04, KEY_06_01, KEY_06_02, KEY_06_03, KEY_06_04: MOMENTARY-SWITCH-SPST-PTH-6.0MM; TACTILE_SWITCH_PTH_6.0MM
S1, S2: ENCODER-SWITCH; ROTARY_ENC_PLAIN
TP1, TP2, TP3, TP4, TP5, TP6, TP7, TP8, TP9, TP10, TP11, TP12, TP13: TPSQTP18SQ; TP18SQ

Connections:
ENC1_CHA: JP1.9, S1.A, TP9.TP
ENC1_CHB: JP1.10, S1.B, TP10.TP
ENC2_CHA: JP1.11, S2.A, TP11.TP
ENC2_CHB: JP1.12, S2.B, TP12.TP
GND: JP1.13, KEY_01_01.3 (2), KEY_01_02.3 (2), KEY_01_03.3 (2), KEY_01_04.3 (2), KEY_02_01.3 (2), KEY_02_02.3 (2), KEY_02_03.3 (2), KEY_02_04.3 (2), KEY_03_01.3 (2), KEY_03_02.3 (2), KEY_03_03.3 (2), KEY_03_04.3 (2), KEY_04_01.3 (2), KEY_04_02.3 (2), KEY_04_03.3 (2), KEY_04_04.3 (2), KEY_05_01.3 (2), KEY_05_02.3 (2), KEY_05_03.3 (2), KEY_05_04.3 (2), KEY_06_01.3 (2), KEY_06_02.3 (2), KEY_06_03.3 (2), KEY_06_04.3 (2), S1.C, S1.SW-, S2.C, S2.SW-, TP13.TP
KEY_01: JP1.1, KEY_01_01.1, KEY_01_02.1, KEY_01_03.1, KEY_01_04.1, TP1.TP
KEY_02: JP1.2, KEY_02_01.1, KEY_02_02.1, KEY_02_03.1, KEY_02_04.1, TP2.TP
KEY_03: JP1.3, KEY_03_01.1, KEY_03_02.1, KEY_03_03.1, KEY_03_04.1, TP3.TP
KEY_04: JP1.4, KEY_04_01.1, KEY_04_02.1, KEY_04_03.1, KEY_04_04.1, TP4.TP
KEY_05: JP1.5, KEY_05_01.1, KEY_05_02.1, KEY_05_03.1, KEY_05_04.1, TP5.TP
KEY_06: JP1.6, KEY_06_01.1, KEY_06_02.1, KEY_06_03.1, KEY_06_04.1, TP6.TP
KEY_07: JP1.7, S1.SW+, TP7.TP
KEY_08: JP1.8, S2.SW+, TP8.TP

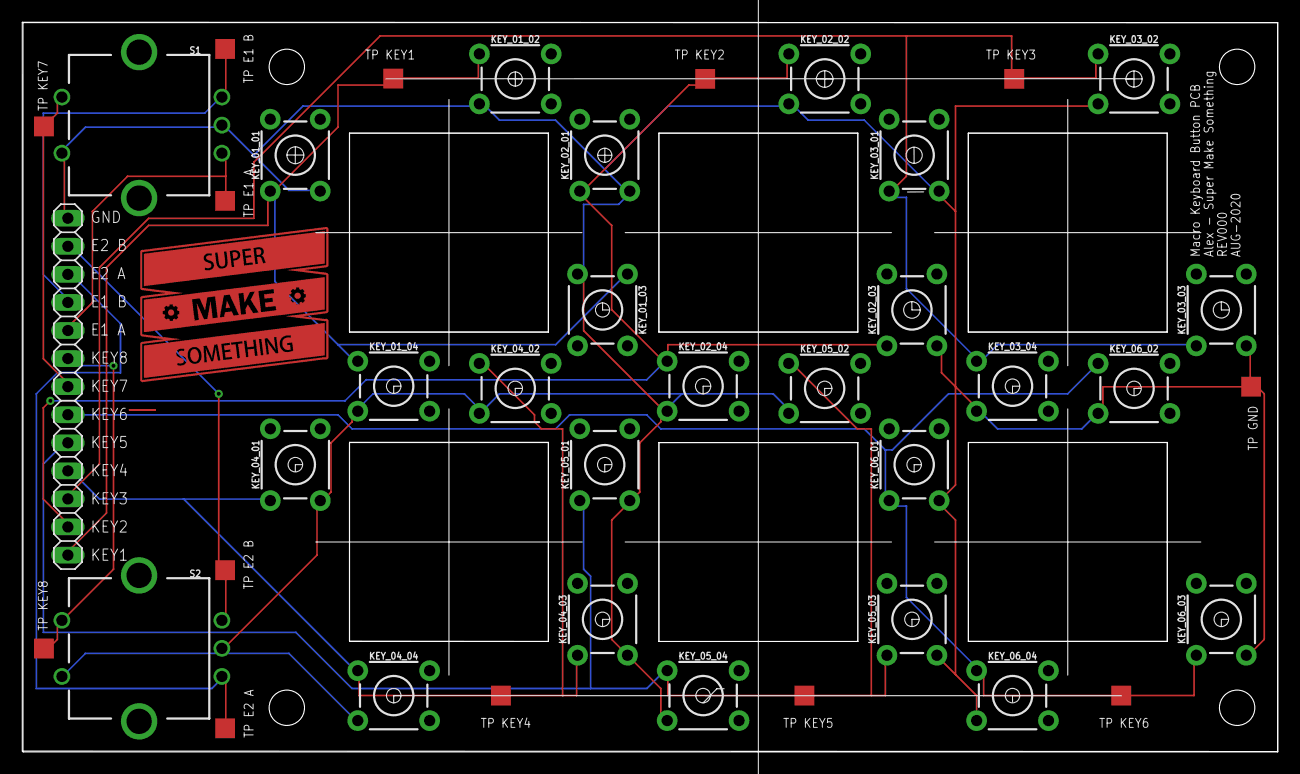
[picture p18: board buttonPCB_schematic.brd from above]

Board: 2 copper layers, 113.6 x 66.0 mm, 40 parts (0 on the bottom side), 13 nets.

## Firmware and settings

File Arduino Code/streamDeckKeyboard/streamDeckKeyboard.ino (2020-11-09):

/* DIY Stream Deck Keyboard Code (DIY Stream Deck - Super Make Something Episode 22)
 * by: Alex - Super Make Something
 * date: November 8th, 2020
 * license: Creative Commons - Attribution - Non-Commercial.  More information available at: http://creativecommons.org/licenses/by-nc/3.0/
 */

#define ENCODER_DO_NOT_USE_INTERRUPTS
#include <Keyboard.h>
#include <Encoder.h>

Encoder upDown(10,15);
Encoder leftRight(14,16);

char buttonArray1[] = {'a','b','c','d','e','s','g','h','i'}; //Array to save button presses
char buttonArray2[] = {'j','k','l','m','n','o','p','q','r'}; // Add additional arrays for more pages

int pageFlag = 1; // Flag for button pages

const int buttonPin2 = 2;
const int buttonPin3 = 3;
const int buttonPin4 = 4;
const int buttonPin5 = 5;
const int buttonPin6 = 6;
const int buttonPin7 = 7;
const int buttonPin8 = 8;
const int buttonPin9 = 9;

int pressedPin2 = HIGH;
int pressedPin3 = HIGH;
int pressedPin4 = HIGH;
int pressedPin5 = HIGH;
int pressedPin6 = HIGH;
int pressedPin7 = HIGH;
int pressedPin8 = HIGH; //Encoder Button 1 
int pressedPin9 = HIGH; //Encoder Button 2

int lastState2 = HIGH;
int lastState3 = HIGH;
int lastState4 = HIGH;
int lastState5 = HIGH;
int lastState6 = HIGH;
int lastState7 = HIGH;
int lastState8 = HIGH;
int lastState9 = HIGH;

unsigned long lastDebounceTime2 = 0; // Last time the button was pressed
unsigned long lastDebounceTime3 = 0;
unsigned long lastDebounceTime4 = 0;
unsigned long lastDebounceTime5 = 0;
unsigned long lastDebounceTime6 = 0;
unsigned long lastDebounceTime7 = 0;
unsigned long lastDebounceTime8 = 0;
unsigned long lastDebounceTime9 = 0;

long posUpDown = 0; //Position counter for up/down encoder
long posLeftRight = 0; //Position counter for left/right encoder
long posUpDownPrev = 0; //Previous position of up/down encoder
long posLeftRightPrev = 0; //Previous position of left/right encoder

int counterUpDown = 0;
int counterLeftRight = 0;

void setup() 
{
  Serial.print("Initializing Pins...");
  pinMode(buttonPin2, INPUT_PULLUP);
  pinMode(buttonPin3, INPUT_PULLUP);
  pinMode(buttonPin4, INPUT_PULLUP);
  pinMode(buttonPin5, INPUT_PULLUP);
  pinMode(buttonPin6, INPUT_PULLUP);
  pinMode(buttonPin7, INPUT_PULLUP);
  pinMode(buttonPin8, INPUT_PULLUP);
  pinMode(buttonPin9, INPUT_PULLUP);
  
  Serial.println(" Done!");

  Serial.print("Initializing Keyboard...");
  Keyboard.begin();
  Serial.println(" Done!");

  delay(50);

  digitalWrite(A0, LOW);
  
  Serial.println("Setup Complete!");
}

void loop() 
{
  
  pressedPin2 = digitalRead(2);
  pressedPin3 = digitalRead(3);
  pressedPin4 = digitalRead(4);
  pressedPin5 = digitalRead(5);
  pressedPin6 = digitalRead(6);
  pressedPin7 = digitalRead(7);
  pressedPin8 = digitalRead(8);
  pressedPin9 = digitalRead(9);

 // BUTTONS
 if (pressedPin2 != lastState2)
  {
    if (pressedPin2 == LOW)
    {
      switch (pageFlag) //Depending on pageFlag, send different keystroke
      {
        case 1:
          Keyboard.press(buttonArray1[0]); // Send keystroke
          break;
        default:
          Keyboard.press(buttonArray2[0]);
          break;
      }
    }
  }

  if (pressedPin3 != lastState3) // Button 3 assigned to page select
  {
    if (pressedPin3 == LOW)
    {
      if (pageFlag == 1)
      {
        pageFlag = 2;
        digitalWrite(A0, HIGH);
      }
      else if (pageFlag == 2)
      {
        pageFlag = 1;
        digitalWrite(A0, LOW);
      }
    }
  }
  Serial.print("Page Flag: ");
  Serial.println(pageFlag);

  if (pressedPin4 != lastState4)
  {
    if (pressedPin4 == LOW)
    {
      switch (pageFlag) //Depending on pageFlag, send different keystroke
      {
        case 1:
          Keyboard.press(buttonArray1[2]); // Send keystroke
          break;
        default:
          Keyboard.press(buttonArray2[2]);
          break;
      }
    }
  }

  if (pressedPin5 != lastState5)
  {
    if (pressedPin5 == LOW)
    {
      switch (pageFlag) //Depending on pageFlag, send different keystroke
      {
        case 1:
          Keyboard.press(buttonArray1[3]); // Send keystroke
          break;
        default:
          Keyboard.press(buttonArray2[3]);
          break;
      }
    }
  }

  if (pressedPin6 != lastState6)
  {
    if (pressedPin6 == LOW)
    {
      switch (pageFlag) //Depending on pageFlag, send different keystroke
      {
        case 1:
          Keyboard.press(buttonArray1[4]); // Send keystroke
          break;
        default:
          Keyboard.press(buttonArray2[4]);
          break;
      }
    }
  }

  if (pressedPin7 != lastState7)
  {
    if (pressedPin7 == LOW)
    {
      switch (pageFlag) //Depending on pageFlag, send different keystroke
      {
        case 1:
          Keyboard.press(buttonArray1[5]); // Send keystroke
          break;
        default:
          Keyboard.press(buttonArray2[5]);
          break;
      }
    }
  }

  if (pressedPin8 != lastState8)
  {
    if (pressedPin8 == LOW)
    {
      switch (pageFlag) //Depending on pageFlag, send different keystroke
      {
        case 1:
          Keyboard.press(buttonArray1[6]); // Send keystroke
          break;
        default:
          Keyboard.press(buttonArray2[6]);
          break;
      }
    }
  }

  if (pressedPin9 != lastState9)
  {
    if (pressedPin9 == LOW)
    {
      switch (pageFlag) //Depending on pageFlag, send different keystroke
      {
        case 1:
          Keyboard.press(buttonArray1[7]); // Send keystroke
          break;
        default:
          Keyboard.press(buttonArray2[7]);
          break;
      } 
    }
  }

  // ENCODERS
  posUpDown = upDown.read(); //Up/down encoder
  if (posUpDown!=posUpDownPrev) //If new position doesn't equal previous position
  {
    if ((posUpDown-posUpDownPrev)>0)
    {
      counterUpDown = counterUpDown+1;
      if (counterUpDown>3) // 3 counts per physical encoder "click"
      {
        Keyboard.press(KEY_UP_ARROW);
        counterUpDown = 0;
        Keyboard.releaseAll();
      }
    }
    else if ((posUpDown-posUpDownPrev)<0)
    {
      counterUpDown = counterUpDown-1;
      if (counterUpDown<-3)
      {
        Keyboard.press(KEY_DOWN_ARROW);
        counterUpDown = 0;
        Keyboard.releaseAll();
      }
    }
  }
  Keyboard.releaseAll();
  posUpDownPrev = posUpDown;
  //Serial.println(counterUpDown);

  posLeftRight = leftRight.read(); // Left/right encoder
  if (posLeftRight!=posLeftRightPrev) //If new position doesn't equal previous position
  {
    if ((posLeftRight-posLeftRightPrev)>0)
    {
      counterLeftRight = counterLeftRight+1;
      if (counterLeftRight>3) // 3 counts per physical encoder "click"
      {
        Keyboard.press(KEY_RIGHT_ARROW);
        counterLeftRight = 0;
        Keyboard.releaseAll();
      }
    }
    else if ((posLeftRight-posLeftRightPrev)<0)
    {
      counterLeftRight = counterLeftRight-1;
      if (counterLeftRight<-3)
      {
        Keyboard.press(KEY_LEFT_ARROW);
        counterLeftRight = 0;
        Keyboard.releaseAll();
      }
    }
  }
  Keyboard.releaseAll();
  posLeftRightPrev = posLeftRight;
  Serial.println(counterLeftRight);


  // BUTTON STATE MANAGEMENT
  lastState2 = pressedPin2; // Save the latest reading
  lastState3 = pressedPin3;
  lastState4 = pressedPin4;
  lastState5 = pressedPin5;
  lastState6 = pressedPin6;
  lastState7 = pressedPin7;
  lastState8 = pressedPin8;
  lastState9 = pressedPin9;
  
  Keyboard.releaseAll(); // Release all pressed keys
}

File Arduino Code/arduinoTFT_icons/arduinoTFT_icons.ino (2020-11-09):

/* DIY Stream Deck LCD Screen Code (DIY Stream Deck - Super Make Something Episode 22)
 * by: Alex - Super Make Something
 * date: November 8th, 2020
 * license: Creative Commons - Attribution - Non-Commercial.  More information available at: http://creativecommons.org/licenses/by-nc/3.0/
 */

#include "SD.h"
#include <SPI.h>
#include <LCDWIKI_GUI.h> //Core graphics library
#include <LCDWIKI_KBV.h> //Hardware-specific library

//Initialize my_lcd object
LCDWIKI_KBV my_lcd(ILI9486,A3,A2,A1,A0,A4); //model,cs,cd,wr,rd,reset

#define  BLACK   0x0000
#define BLUE    0x001F
#define RED     0xF800
#define GREEN   0x07E0
#define CYAN    0x07FF
#define MAGENTA 0xF81F
#define YELLOW  0xFFE0
#define WHITE   0xFFFF

#define PIXEL_NUMBER  1 //(my_lcd.Get_Display_Width()/4)
#define FILE_NUMBER 7
#define FILE_NAME_SIZE_MAX 20

int LOADED = 0;
int imageSize = 120;
int gridSpacing = 62;

int inputPin = A7;
int pageFlag = 0;
int pageFlagCurrent = 3;

uint32_t bmp_offset = 0;
uint16_t s_width = my_lcd.Get_Display_Width();  
uint16_t s_height = my_lcd.Get_Display_Height();
//int16_t PIXEL_NUMBER;

char file_name[FILE_NUMBER][FILE_NAME_SIZE_MAX]; // char arrays that define filenames
char file_name2[FILE_NUMBER][FILE_NAME_SIZE_MAX];

uint16_t read_16(File fp)
{
    uint8_t low;
    uint16_t high;
    low = fp.read();
    high = fp.read();
    return (high<<8)|low;
}

uint32_t read_32(File fp)
{
    uint16_t low;
    uint32_t high;
    low = read_16(fp);
    high = read_16(fp);
    return (high<<8)|low;   
}
 
bool analysis_bpm_header(File fp)
{
    if(read_16(fp) != 0x4D42)
    {
      return false;  
    }
    //get bpm size
    read_32(fp);
    //get creator information
    read_32(fp);
    //get offset information
    bmp_offset = read_32(fp);
    //get DIB infomation
    read_32(fp);
    //get width and heigh information
    uint32_t bpm_width = read_32(fp);
    uint32_t bpm_heigh = read_32(fp);
    read_16(fp);
    return true;
}

void errorCheck(File bmp_file)
{
   Serial.println("Error checking: ");
   if(!bmp_file)
       {
            my_lcd.Set_Text_Back_colour(BLUE);
            my_lcd.Set_Text_colour(WHITE);    
            my_lcd.Set_Text_Size(1);
            my_lcd.Print_String("didnt find BMPimage!",0,10);
            while(1);
        }
        if(!analysis_bpm_header(bmp_file))
        {  
            my_lcd.Set_Text_Back_colour(BLUE);
            my_lcd.Set_Text_colour(WHITE);    
            my_lcd.Set_Text_Size(1);
            my_lcd.Print_String("bad bmp picture!",0,0);
            return;
        }
   Serial.println("No error: ");
}


void draw_bmp_picture(File fp)
{
  uint16_t i,j,k,l,m=0;
  uint8_t bpm_data[PIXEL_NUMBER*3] = {0};
  uint16_t bpm_color[PIXEL_NUMBER];
  fp.seek(bmp_offset);
  for(i = 0; i<s_height; i++)
  {
    for(j = 0;j<s_width/PIXEL_NUMBER;j++)
    {
      m = 0;
      fp.read(bpm_data,PIXEL_NUMBER*3);
      for(k = 0;k<PIXEL_NUMBER;k++)
      {
        bpm_color[k]= my_lcd.Color_To_565(bpm_data[m+2], bpm_data[m+1], bpm_data[m+0]); //change to 565
        m +=3;
      }
      for(l = 0;l<PIXEL_NUMBER;l++)
      {
        my_lcd.Set_Draw_color(bpm_color[l]);
        my_lcd.Draw_Pixel(j*PIXEL_NUMBER+l,(s_height-1)-i);
      }    
     }
   }    
}


void draw_icon(File bmp_file, int xLoc, int yLoc)
{
  uint16_t i,j,k,l,m = 0;
  uint8_t bpm_data[PIXEL_NUMBER*3] = {0};
  uint16_t bpm_color[PIXEL_NUMBER];
  bmp_file.seek(bmp_offset);
  for(i = xLoc; i<xLoc+imageSize; i++)
  {
    for(j = yLoc; j<(yLoc+imageSize); j++)
    {
      m = 0;
      bmp_file.read(bpm_data,PIXEL_NUMBER*3);
      
      bpm_color[0]= my_lcd.Color_To_565(bpm_data[2], bpm_data[1], bpm_data[0]); //change to 565

      my_lcd.Draw_Pixe(j,(s_height)-i,bpm_color[0]);
     }
   }
  bmp_file.close();     
}

void setup() 
{
  Serial.begin(9600);
  my_lcd.Init_LCD();
  Serial.println(my_lcd.Read_ID(), HEX);
  my_lcd.Fill_Screen(BLACK);

  strcpy(file_name[0],"splash.bmp"); //Define filenames on SD Card - page 1
  strcpy(file_name[1],"01.bmp");
  strcpy(file_name[2],"02.bmp");
  strcpy(file_name[3],"03.bmp");
  strcpy(file_name[4],"04.bmp");
  strcpy(file_name[5],"05.bmp");
  strcpy(file_name[6],"06.bmp");
  
  strcpy(file_name2[0],"splash.bmp"); //Define filenames on SD Card - page 2
  strcpy(file_name2[1],"07.bmp");
  strcpy(file_name2[2],"08.bmp");
  strcpy(file_name2[3],"09.bmp");
  strcpy(file_name2[4],"10.bmp");
  strcpy(file_name2[5],"11.bmp");
  strcpy(file_name2[6],"12.bmp");
  
  //Init SD_Card
  pinMode(10, OUTPUT);
  delay(100);
  
  if (!SD.begin(SS)) //SD Card Initialization Error
  {
    my_lcd.Set_Text_Back_colour(BLUE);
    my_lcd.Set_Text_colour(WHITE);    
    my_lcd.Set_Text_Size(1);
    my_lcd.Print_String("SD Card Init fail!",0,0);
  }
  else
  {
    /*
    //Display splash screen
    File bmp_file;
    bmp_file = SD.open(file_name[0]);
    errorCheck(bmp_file);
    draw_bmp_picture(bmp_file);
    bmp_file.close();
    delay(1000); // Display splash screen for 10 seconds
    */
  }
}

void loop() 
{
    
    int i = 0;
    File bmp_file;
    int xLoc[] = {0, gridSpacing+imageSize, 2*(gridSpacing+imageSize), 0, gridSpacing+imageSize, 2*(gridSpacing+imageSize)};
    int yLoc[] = {0, 0, 0, 62+imageSize, 62+imageSize, 62+imageSize};
    
    while(1)
    {
      int currentVal = analogRead(inputPin);
      //Serial.println("Data Loaded!");
      Serial.println(currentVal);
      if (currentVal<512) // Add additional if statements for more pages
      {
        pageFlag=1;
        if (pageFlag!=pageFlagCurrent)
        {
          for (i = 1; i<FILE_NUMBER; i++)
          {
            bmp_file = SD.open(file_name[i]);
            //Serial.print(file_name[1]);
            errorCheck(bmp_file);
            draw_icon(bmp_file, xLoc[i-1], yLoc[i-1]);
          }
          pageFlagCurrent=pageFlag;
        }
      }
      else
      {
        pageFlag=2;
        if (pageFlag!=pageFlagCurrent)
        {
          for (i = 1; i<FILE_NUMBER; i++)
          {
            bmp_file = SD.open(file_name2[i]);
            //Serial.print(file_name[1]);
            errorCheck(bmp_file);
            draw_icon(bmp_file, xLoc[i-1], yLoc[i-1]);
          }
          pageFlagCurrent=pageFlag;
        }
      }
    }
}

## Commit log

2020-11-09 Added Gerber files
2020-11-11 Added board and schematic files
    [buttonPCB_schematic.brd, buttonPCB_schematic.sch, lcdPCB_schematic.brd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]
2020-11-11 Added BoM and link to video
2020-11-11 Added link to STL files
2020-12-12 Added STL and STEP files
    [PM-1001a - Housing.step, PM-1001a - Housing.stl, PM-1001b - Voronoi Housing.step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]

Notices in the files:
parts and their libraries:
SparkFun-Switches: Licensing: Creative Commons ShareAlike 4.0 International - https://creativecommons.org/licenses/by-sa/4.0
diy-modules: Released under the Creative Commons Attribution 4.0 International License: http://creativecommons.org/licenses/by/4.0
